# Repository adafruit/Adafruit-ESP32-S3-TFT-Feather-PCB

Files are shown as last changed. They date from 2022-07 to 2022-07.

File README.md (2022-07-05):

## Adafruit ESP32-S3 TFT Feather PCB

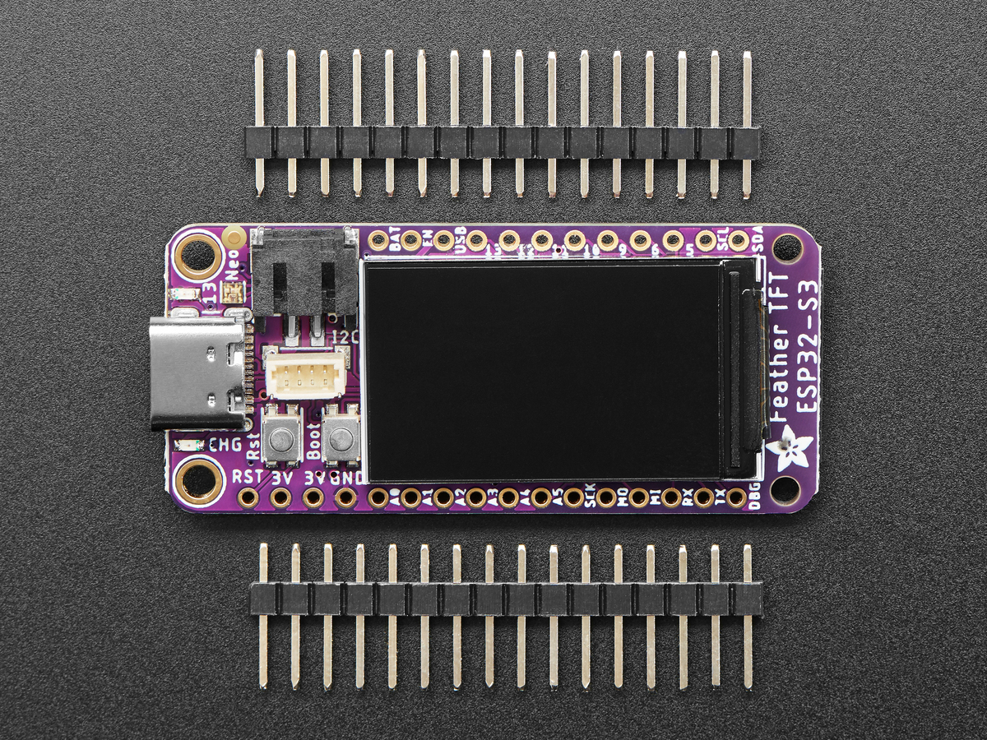
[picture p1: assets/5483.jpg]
<a href="http://www.adafruit.com/products/5483"><br/>
Click here to purchase one from the Adafruit shop</a>

PCB files for the Adafruit ESP32-S3 TFT Feather. 

Format is EagleCAD schematic and board layout
* https://www.adafruit.com/product/5483

### Description

We've got a new machine here at Adafruit, it can uncover your deepest desires. Don't believe me? I'll turn it on right now to prove it to you! What, you want your very own soft serve ice cream machine? OK well, that's not something we can provide. But we can provide your second-deepest desire: an ESP32-S3 Feather board with a built in IPS TFT color display. It's got all the ~~delicious creamy goodness~~ features of a Feather main board, the comforting warmth of an ESP32-S3 WiFi+BLE microcontroller, and the crispness of a 240x135 pixel color TFT display. All that and it will even plug in nicely into a breadboard, terminal block wing, or Feather Doubler or even just stack on top of another wing.

This Feather comes with native USB and 4 MB Flash + 2 MB of PSRAM, so it is perfect for use with CircuitPython or Arduino with low-cost WiFi. Native USB means it can act like a keyboard or a disk drive. WiFi means it's awesome for IoT projects. And Feather means it works with the large community of Feather Wings for expandability.

The ESP32-S3 is a highly-integrated, low-power, 2.4 GHz Wi-Fi/BLE System-on-Chip (SoC) solution that has built-in native USB as well as some other interesting new technologies like Time of Flight distance measurements and AI acceleration. With its state-of-the-art power and RF performance, this SoC is an ideal choice for a wide variety of application scenarios relating to the Internet of Things (IoT), wearable electronics, and smart homes.

The Feather ESP32-S3 has a dual-core 240 MHz chip, so it is comparable to ESP32's dual-core. However, there is no Bluetooth Classic support, only Bluetooth LE. This chip is a great step up from the earlier ESP32-S2! This ESP32-S3 mini-module we are using on the Feather comes with 4 MB flash and 2 MB PSRAM, as well as lots of 512KB of SRAM so it's perfect for use with CircuitPython support or any time massive buffers are needed: for fast memory access use SRAM, for slower-but-roomier access use PSRAM. It's also great for use in ESP-IDF or with Arduino support.

The color TFT is connected to the SPI pins and uses additional pins for control that are not exposed to the breakout pads. It's the same display as you see here, with 240x135 pixels and is IPS so you get bright color at any angle. The backlight is also connected to a separate pin so you can PWM the backlight up and down as desired.

For low power usages, the Feather has a second low-dropout 3.3V regulator. The regulator is controlled with a GPIO pin on the enable line and can shut off power to the Stemma QT port and TFT. There is also a separate power pin for the NeoPixel that can be used to disable it for even lower quiescent power. With everything off and in deep sleep mode, the TFT feather uses about 100uA of current.

### License

Adafruit invests time and resources providing this open source design, please support Adafruit and open-source hardware by purchasing products from [Adafruit](https://www.adafruit.com)!

Designed by Limor Fried/Ladyada for Adafruit Industries.

Creative Commons Attribution/Share-Alike, all text above must be included in any redistribution. 
See license.txt for additional details.

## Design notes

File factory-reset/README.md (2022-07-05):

## Factory Reset file - ESP32-S3 TFT Feather

This is the factory reset file for the ESP32-S3 TFT Feather.

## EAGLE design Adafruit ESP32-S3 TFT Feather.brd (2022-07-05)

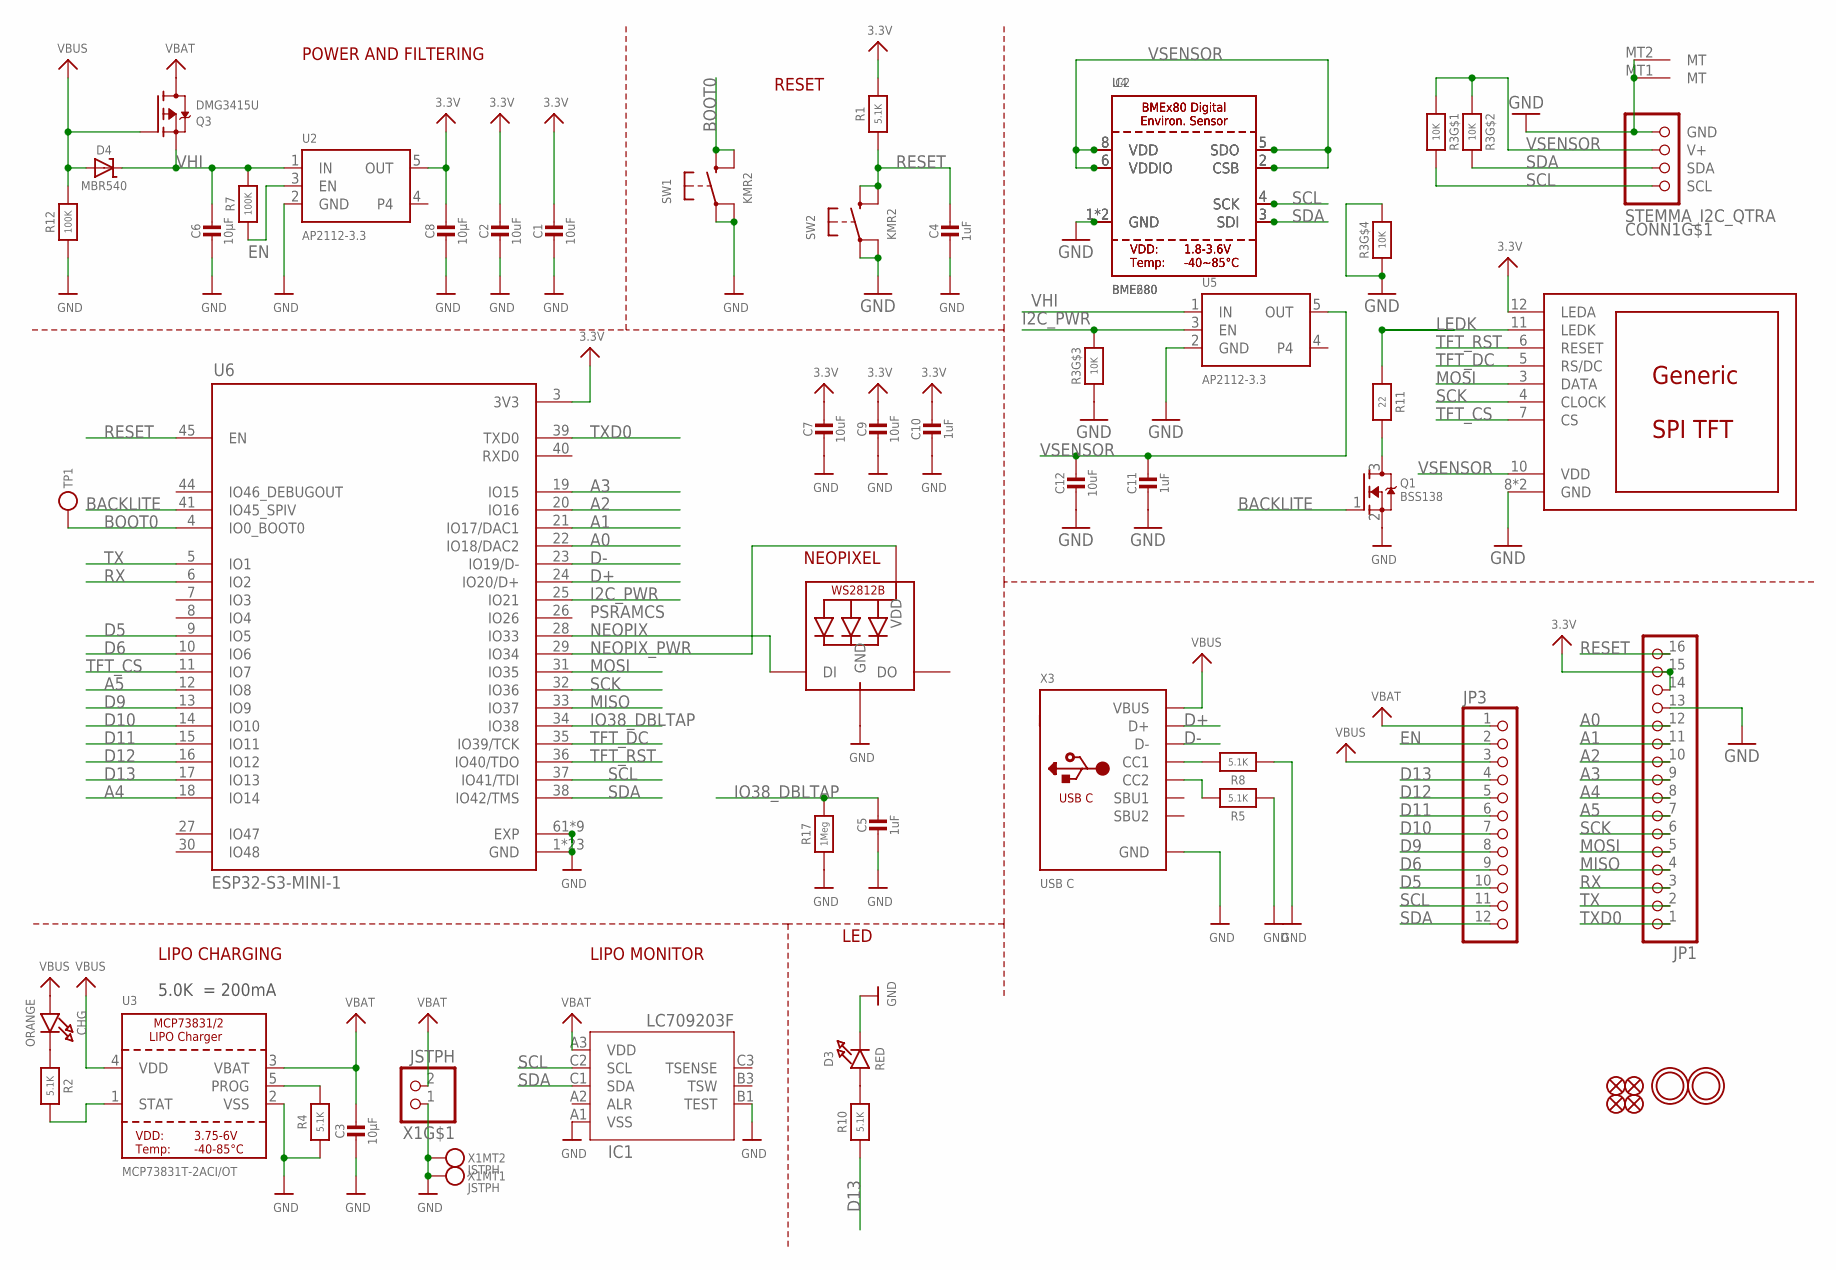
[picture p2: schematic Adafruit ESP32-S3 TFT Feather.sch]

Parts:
C1, C2, C7, C9, C12: 10uF; 0805-NO
C3, C6, C8: 10µF; 0805-NO
C4, C5, C10, C11: 1uF; 0603-NO
CHG: ORANGE; CHIPLED_0603_NOOUTLINE
CONN1: STEMMA_I2C_QTRA; JST_SH4_RA
D3: RED; CHIPLED_0603_NOOUTLINE
D4: MBR540; SOD-123
DISP1: DISP_LCD_GENERIC_SPI_1.14IN_240X135_WRAPUNDER; TFT_1.14IN_240X135_WRAPUNDER
IC1: LC709203F/MH; WLCSP9
IC2: BME680
JP1: HEADER-1X16_MIN; 1X16_ROUND_MIN
JP3: HEADER-1X12_MIN; 1X12_ROUND_MIN
LED1: WS2812B_SK6805_1515; SK6805_1515
Q1: BSS138; SOT23-R
Q3: DMG3415U; SOT23-R
R1, R2, R4, R5, R8, R10: 5.1K; 0603-NO
R3: 10K; RESPACK_4X0603
R7, R12: 100K; 0603-NO
R11: 22; 0603-NO
R17: 1Meg; 0603-NO
SW1, SW2: KMR2; BTN_KMR2_4.6X2.8
TP1: TESTPOINTROUND1.5MMNO; TESTPOINT_ROUND_1.5MM_NO
U2, U5: AP2112-3.3; SOT23-5
U3: MCP73831T-2ACI/OT; SOT23-5
U4: BME280
U6: ESP32-S3-MINI-1; QFN60_ESP32-S2-MINI-1_EXP
U$31, U$32: MOUNTINGHOLE2.5; MOUNTINGHOLE_2.5_PLATED
U$34, U$35, U$55, U$56: FIDUCIAL_1MM
X1: JSTPH; JSTPH2_BATT
X3: USB C; USB_C_CUSB31-CFM2AX-01-X

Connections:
3.3V: C1.1, C2.1, C7.1, C8.1, C9.1, C10.1, DISP1.12 (LEDA), JP1.14, JP1.15, R1.2, U2.5 (OUT), U6.3 (3V3)
A0: JP1.12, U6.22 (IO18/DAC2)
A1: JP1.11, U6.21 (IO17/DAC1)
A2: JP1.10, U6.20 (IO16)
A3: JP1.9, U6.19 (IO15)
A4: JP1.8, U6.18 (IO14)
A5: JP1.7, U6.12 (IO8)
BACKLITE: Q1.1 (G), U6.41 (IO45_SPIV)
BOOT0: SW1.B (S), SW1.B' (S1), TP1.P$1, U6.4 (IO0_BOOT0)
D5: JP3.10, U6.9 (IO5)
D6: JP3.9, U6.10 (IO6)
D9: JP3.8, U6.13 (IO9)
D10: JP3.7, U6.14 (IO10)
D11: JP3.6, U6.15 (IO11)
D12: JP3.5, U6.16 (IO12)
D13: JP3.4, R10.1, U6.17 (IO13)
D+: U6.24 (IO20/D+), X3.A6 (D+), X3.B6 (D+)
D-: U6.23 (IO19/D-), X3.A7 (D-), X3.B7 (D-)
EN: JP3.2, R7.1, U2.3 (EN)
GND: C1.2, C2.2, C3.2, C4.2, C5.2, C6.2, C7.2, C8.2, C9.2, C10.2, C11.2, C12.2, CONN1.1 (GND), CONN1.MT1 (MT), CONN1.MT2 (MT), D3.C, DISP1.8 (GND), DISP1.13 (GND), IC1.A1 (VSS), IC1.B1 (TEST), IC2.1 (GND), IC2.7 (GND), JP1.13, LED1.4 (GND), Q1.2 (S), R3.3 (1), R3.4 (1), R3.5 (2), R4.1, R5.1, R8.1, R12.1, R17.1, SW1.A, SW1.A' (P1), SW2.A, SW2.A' (P1), U2.2 (GND), U3.2 (VSS), U4.1 (GND), U4.7 (GND), U5.2 (GND), U6.1 (GND), U6.2 (GND), U6.42 (GND), U6.43 (GND), U6.46 (GND), U6.47 (GND), U6.48 (GND), U6.49 (GND), U6.50 (GND), U6.51 (GND), U6.52 (GND), U6.53 (GND), U6.54 (GND), U6.55 (GND), U6.56 (GND), U6.57 (GND), U6.58 (GND), U6.59 (GND), U6.60 (GND), U6.61 (EXP), U6.62 (GND), U6.63 (GND), U6.64 (GND), U6.65 (GND), U6.66 (EXP), U6.67 (EXP), U6.68 (EXP), U6.69 (EXP), U6.70 (EXP), U6.71 (EXP), U6.72 (EXP), U6.73 (EXP), X1.1, X1.NC1, X1.NC2, X3.A1B12 (GND), X3.B1A12 (GND)
I2C_PWR: R3.6 (2), U5.3 (EN), U6.25 (IO21)
IO38_DBLTAP: C5.1, R17.2, U6.34 (IO38)
LEDK: DISP1.11 (LEDK), R11.1
MISO: JP1.4, U6.33 (IO37)
MOSI: DISP1.3 (DATA), JP1.5, U6.31 (IO35)
unnamed: CHG.C, R2.1
unnamed: Q1.3 (D), R11.2
unnamed: R2.2, U3.1 (STAT)
unnamed: R4.2, U3.5 (PROG)
unnamed: D3.A, R10.2
unnamed: R8.2, X3.A5 (CC1)
unnamed: R5.2, X3.B5 (CC2)
NEOPIX: LED1.1 (DI), U6.28 (IO33)
NEOPIX_PWR: LED1.2 (VDD), U6.29 (IO34)
RESET: C4.1, JP1.16, R1.1, SW2.B (S), SW2.B' (S1), U6.45 (EN)
RX: JP1.3, U6.6 (IO2)
SCK: DISP1.4 (CLOCK), JP1.6, U6.32 (IO36)
SCL: CONN1.4 (SCL), IC1.C2 (SCL), IC2.4 (SCK), JP3.11, R3.8 (2), U4.4 (SCK), U6.37 (IO41/TDI)
SDA: CONN1.3 (SDA), IC1.C1 (SDA), IC2.3 (SDI), JP3.12, R3.7 (2), U4.3 (SDI), U6.38 (IO42/TMS)
TFT_CS: DISP1.7 (CS), U6.11 (IO7)
TFT_DC: DISP1.5 (RS/DC), U6.35 (IO39/TCK)
TFT_RST: DISP1.6 (RESET), U6.36 (IO40/TDO)
TX: JP1.2, U6.5 (IO1)
TXD0: JP1.1, U6.39 (TXD0)
VBAT: C3.1, IC1.A3 (VDD), JP3.1, Q3.3 (D), U3.3 (VBAT), X1.2
VBUS: CHG.A, D4.A, JP3.3, Q3.1 (G), R12.2, U3.4 (VDD), X3.A4B9 (VBUS), X3.B4A9 (VBUS)
VHI: C6.1, D4.C, Q3.2 (S), R7.2, U2.1 (IN), U5.1 (IN)
VSENSOR: C11.1, C12.1, CONN1.2 (V+), DISP1.10 (VDD), IC2.2 (CSB), IC2.5 (SDO), IC2.6 (VDDIO), IC2.8 (VDD), R3.1, R3.2 (1), U4.2 (CSB), U4.5 (SDO), U4.6 (VDDIO), U4.8 (VDD), U5.5 (OUT)

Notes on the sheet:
POWER AND FILTERING
RESET
5.0K = 200mA
LIPO CHARGING
LED
PSRAMCS
NEOPIXEL
LIPO MONITOR

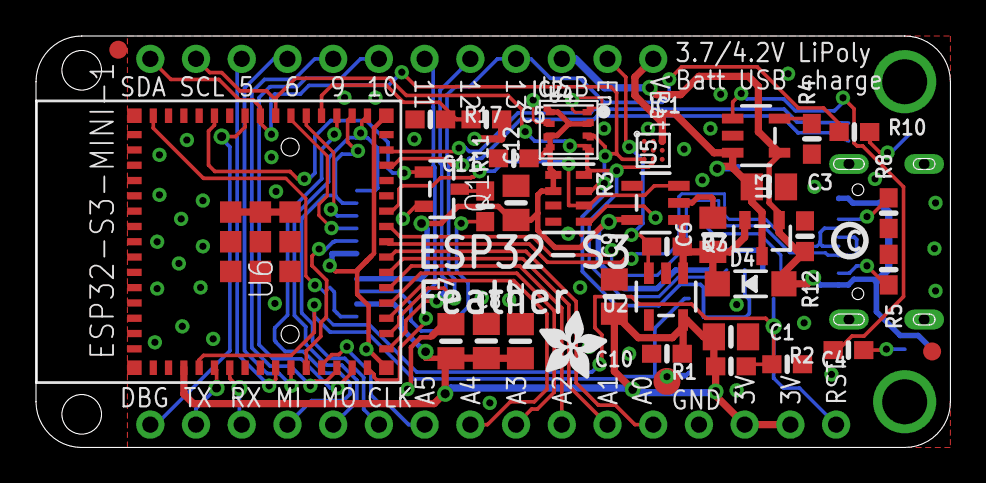
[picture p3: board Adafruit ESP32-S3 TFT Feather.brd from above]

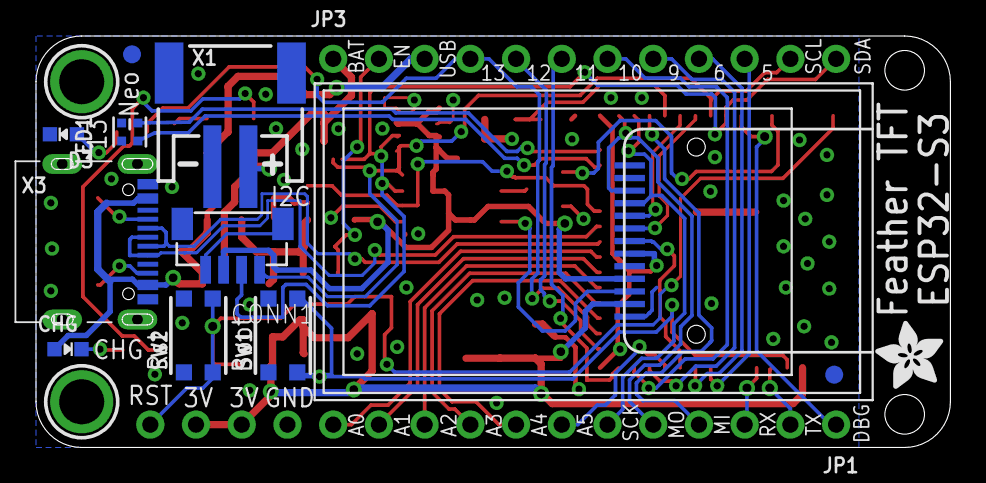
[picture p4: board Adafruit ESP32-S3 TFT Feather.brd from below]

Board: 2 copper layers, 50.8 x 22.9 mm, 54 parts (16 on the bottom side), 48 nets.

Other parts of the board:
U$7: PCBFEAT-REV-040
U$9, U$54: ADAFRUIT_3.5MM

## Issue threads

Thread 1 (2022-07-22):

Unable to find the factory reset file in here

techman44, 2022-07-22:
[README.md](https://github.com/adafruit/Adafruit-ESP32-S3-TFT-Feather-PCB/tree/main/factory-reset#readme)
Factory Reset file - ESP32-S3 TFT Feather

This is the factory reset file for the ESP32-S3 TFT Feather.

But there is no file attached here.

scottmc, 2023-01-11:
Looks like this was fixed with b9d6e64ff76f12f86c473061b702d037a3398257 ?

caternuson, 2023-08-17:
Yes it was, along with some other commits to update them. Closing since files are in repo now. Also available here:
https://learn.adafruit.com/adafruit-esp32-s3-tft-feather/factory-reset

Closed 2023-08-17.

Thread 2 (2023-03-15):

What is the expected content on TFT display for ESP32-S3 TFT Feather after performing Factory Reset Firmware UF2?

przemoc, 2023-03-15:
What is the expected content on TFT display for ESP32-S3 TFT Feather connected only to PC via USB after performing [Factory Reset Firmware UF2](https://learn.adafruit.com/adafruit-esp32-s3-tft-feather/factory-reset) using [adafruit-esp32-s3-tft-feather-factory-reset.UF2](https://github.com/adafruit/Adafruit-ESP32-S3-TFT-Feather-PCB/raw/b9d6e64ff76f12f86c473061b702d037a3398257/factory-reset/adafruit-esp32-s3-tft-feather-factory-reset.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) (SHA256: `dbd5238dc04b2db1ccf13ac3cf096f23374979148b53ed1c18fc5ae8631f3696`) and pressing Reset button once?

**Should it be something as shown in [Overview](https://learn.adafruit.com/adafruit-esp32-s3-tft-feather/overview)**
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
**but without Battery and I2C lines?**

I recently bought one. Nothing was shown on TFT display upon connecting to USB. Thankfully after double-click Reset it finally shown something, so TFT display does not seem to malfunction. I realized it had different UF2 (SHA256: `4d4d017eed71962d89f497e535da0872ade7c1b1314bc96bd24366fa43b06a6f`), so I replaced it with UF2 from this repository. But it didn't help (still nothing is shown on TFT display, unless in bootloader mode after double-click Reset). I would like to understand if it is normal behavior or maybe I should be seeing something.

beautifully-br0ken, 2023-08-17:
I am having the same issue with 3 of the 16 boards I ordered. The backlight works but nothing is displayed on the screen even after loading the Feather_ESP32S2_TFT_FactoryTest.ino onto it.

caternuson, 2023-08-17:
Try again with the UF2 files currently hosted in this repo, or available from download here:
https://learn.adafruit.com/adafruit-esp32-s3-tft-feather/factory-reset

File name should be `Adafruit_Feather_ESP32S3_TFT_FactoryTest.uf2` with a sha256 checksum of `b5837f54fafd7ecdcc3267e84e9ad8d7271fad714b86872fad1c1dd0f4edb1bd`

ladyada, 2023-08-20:
@BlitzCityDIY can you re-test your UF2s on both versions (LC709 and MAX17) of the S3 TFT?
https://www.adafruit.com/product/5483

caternuson, 2023-08-21:
FWIW - I did test the UF2 I ref'd above. But only on an older LC709203 Feather variant. (circa Aug 2022 mfg)

beautifully-br0ken, 2023-08-21:
I tried using the UF2 file in this repo (I verified that the checksum was b5837f54fafd7ecdcc3267e84e9ad8d7271fad714b86872fad1c1dd0f4edb1bd) and the screen still will only backlight. When pressing the reset button twice the board shows as FTHRS3BOOT as a drive on my PC but the TFT doesn't display the bootloader screen like it should. After dragging and dropping the UF2 file over  my PC no longer shows FTHRS3BOOT as a drive but the TFT still doesn't display anything. This is happening on both the LC709 and MAX17.

BlitzCityDIY, 2023-08-22:
hihi- i just tested the UF2 on LC and MAX S3 TFT boards and the display is showing the expected text. after uploading the UF2, can you try opening a Serial Monitor in the Arduino IDE for the board to see if the I2C scan is showing up? that is included in the UF2

beautifully-br0ken, 2023-09-08:
After uploading the UF2 I'm seeing this:

16:12:17.921 -> I2C scan: 0x0, 0xB,
16:12:19.949 -> **********************

It continues outputting those same lines every few seconds.

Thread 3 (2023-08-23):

My chip burned I would like to know the type of 2U=N33 chip on the back of pcb.

e145e4, 2023-08-23:
My chip burned when I plugged it into the computer

I would like to know the type of 2U=N33 chip on the back of pcb.

Is it low-dropout 3.3V regulator  ？

thank you

e145e4, 2023-08-23:
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

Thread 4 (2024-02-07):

The Stemma-QT pinout on the pinout PDF is ambiguous

DefProc, 2024-02-07:
While the colour assignments for the socket are correct, the pinout for the plug as indicated is reversed compared to the socket.

from: [Adafruit ESP32-S3 TFT Feather Pinout.pdf](https://github.com/adafruit/Adafruit-ESP32-S3-TFT-Feather-PCB/blob/03490c608b28fda5a84814b96e600051c53e8f6a/Adafruit%20ESP32-S3%20TFT%20Feather%20Pinout.pdf)

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

Ideally, the order of the cable info should be mirrored vertically to match the GND pin 1 of the cable with GND pin 1 of the socket.

I lost more time than I should have figuring out I made up a cable the wrong way round to an external sensor!

caternuson, 2024-02-08:
Thanks for pointing this out. The PDF hosted here (see #5), as well as [source SVG hosted on Adafruit Learn](https://learn.adafruit.com/adafruit-esp32-s3-tft-feather/downloads), have been updated.

Closed 2024-02-07.

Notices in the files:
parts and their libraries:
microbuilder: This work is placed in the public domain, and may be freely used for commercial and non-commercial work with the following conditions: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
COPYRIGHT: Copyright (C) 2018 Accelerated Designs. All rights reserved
